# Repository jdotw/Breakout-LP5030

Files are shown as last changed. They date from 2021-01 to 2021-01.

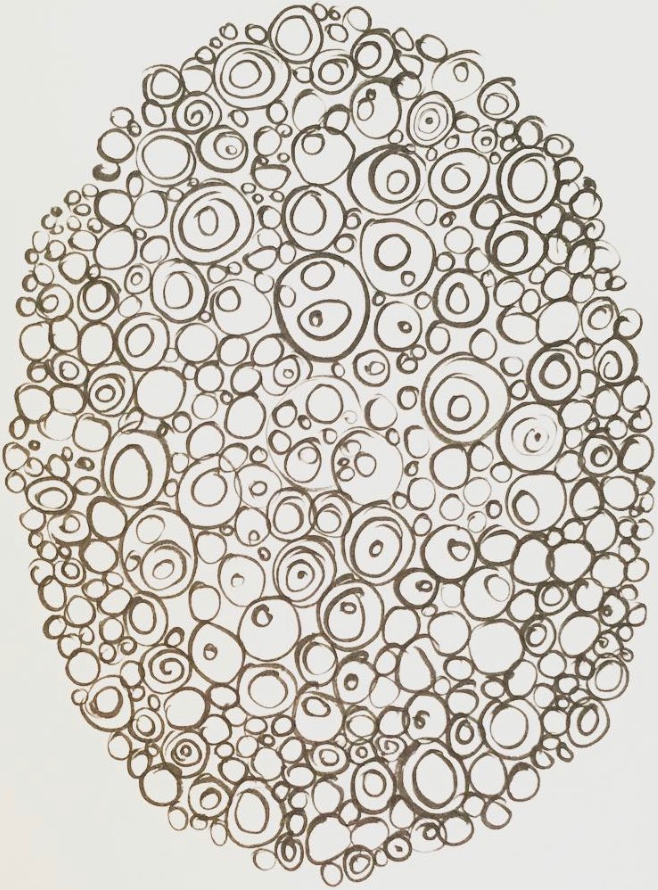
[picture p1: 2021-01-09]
BackImage.png

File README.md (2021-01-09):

# MP2359, LP5030 and TCA9544A Breakout Board

This breakout board allows you to test an LP5030 LED driver, with a TCA9544A i2c mux/hub, being powered by a MP2359 buck power converter. The board was design to be powered by +12V, but should work with anything from +5 to +12. Place a jumper across the 3.3V 2-pin header to enable the use of the onboard power supply. Or, supply 3.3V directly to the pin marked 3.3V to bypass the onboard power supply. 

I built this board because of a larger project where I wanted to use these three components. However, having not used them before in a design and without access to well priced evaluation board, I decided to make my own. TI sells an eval board for the LP5030 but it's $100+ which is ridiculous. There is a well priced board available to eval the MP2359 but it's rather huge. And so, I decided to build my own. 

The gerber and assembly files included herein have been successfully used with JLCPCB and their SMT Assembly surface to order these boards with everything but the LP5030, TCA9544A and headers already assembled. Those, you'll need to take care of yourself. 

If you have any questions you can find me on Twitter @scotchandcode, and streaming regularly at twitch.tv/jdotw. 

Datasheet links:

MP2359: https://www.monolithicpower.com/en/mp2359.html

LP5030: https://www.ti.com/product/LP5030

TCA9544A: https://www.ti.com/product/TCA9544A

Enjoy! 

-jw

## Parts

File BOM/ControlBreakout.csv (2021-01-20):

Comment | Designator | Footprint | LCSC
100nF | C1 | Capacitor_SMD:C_0402_1005Metric | C1525
1uF | C2 | Capacitor_SMD:C_0402_1005Metric | C52923
10uF | C4,C7,C8 | Capacitor_SMD:C_1206_3216Metric | C13585
100nF | C3,C5 | Capacitor_SMD:C_0603_1608Metric | C14663
10nF | C6 | Capacitor_SMD:C_0805_2012Metric | C1710
10uF | C9 | Capacitor_SMD:C_0603_1608Metric | C19702
FM-B2020RGBA-HG | D1,D2,D3,D4,D5,D6,D7,D8,D10,D11 | fm-b2020rgba-hg:FM-B2020RGBA-HG | C108793
LED | D12 | LED_SMD:LED_0603_1608Metric | C72041
B5819W | D9 | Diode_SMD:D_SOD-123 | C8598
500mA | F1 | Fuse:Fuse_1206_3216Metric | C369159
600 @ 600 | FB1 | Inductor_SMD:L_0805_2012Metric | C1017
Conn_01x12 | J1,J2 | Connector_PinHeader_2.54mm:PinHeader_1x12_P2.54mm_Vertical
3v3 Bypass | J3 | Connector_PinHeader_2.54mm:PinHeader_1x02_P2.54mm_Vertical
GND1 | J4 | Connector_PinHeader_2.54mm:PinHeader_1x02_P2.54mm_Vertical
GND2 | J5 | Connector_PinHeader_2.54mm:PinHeader_1x02_P2.54mm_Vertical
Screw_Terminal_01x02 | J6 | TerminalBlock:TerminalBlock_bornier-2_P5.08mm
GND3 | J7 | Connector_PinHeader_2.54mm:PinHeader_1x02_P2.54mm_Vertical
10uH | L1 | Inductor_SMD:L_Sunlord_MWSA0518_5.4x5.2mm | C139506
AO3401A | Q1 | Package_TO_SOT_SMD:SOT-23 | C15127
3.3K | R1 | Resistor_SMD:R_0603_1608Metric | C22978
10K | R2 | Resistor_SMD:R_0603_1608Metric | C25804
100K | R3 | Resistor_SMD:R_1206_3216Metric | C17900
68K | R4 | Resistor_SMD:R_0603_1608Metric | C23231
47K | R5 | Resistor_SMD:R_0603_1608Metric | C25819
15K | R6 | Resistor_SMD:R_0603_1608Metric | C22809
270R | R7 | Resistor_SMD:R_0603_1608Metric | C22966
1K | R8 | Resistor_SMD:R_0603_1608Metric | C21190
100K | R9 | Resistor_SMD:R_0603_1608Metric | C25803
TCA9544A | U1 | Package_SO:TSSOP-20_4.4x6.5mm_P0.65mm
MP2359DJ-LF-Z | U3 | Package_TO_SOT_SMD:TSOT-23-6 | C14259
IS32FL3237-TQLA3-TR | U4 | Package_QFP:TQFP-48-1EP_7x7mm_P0.5mm_EP5x5mm

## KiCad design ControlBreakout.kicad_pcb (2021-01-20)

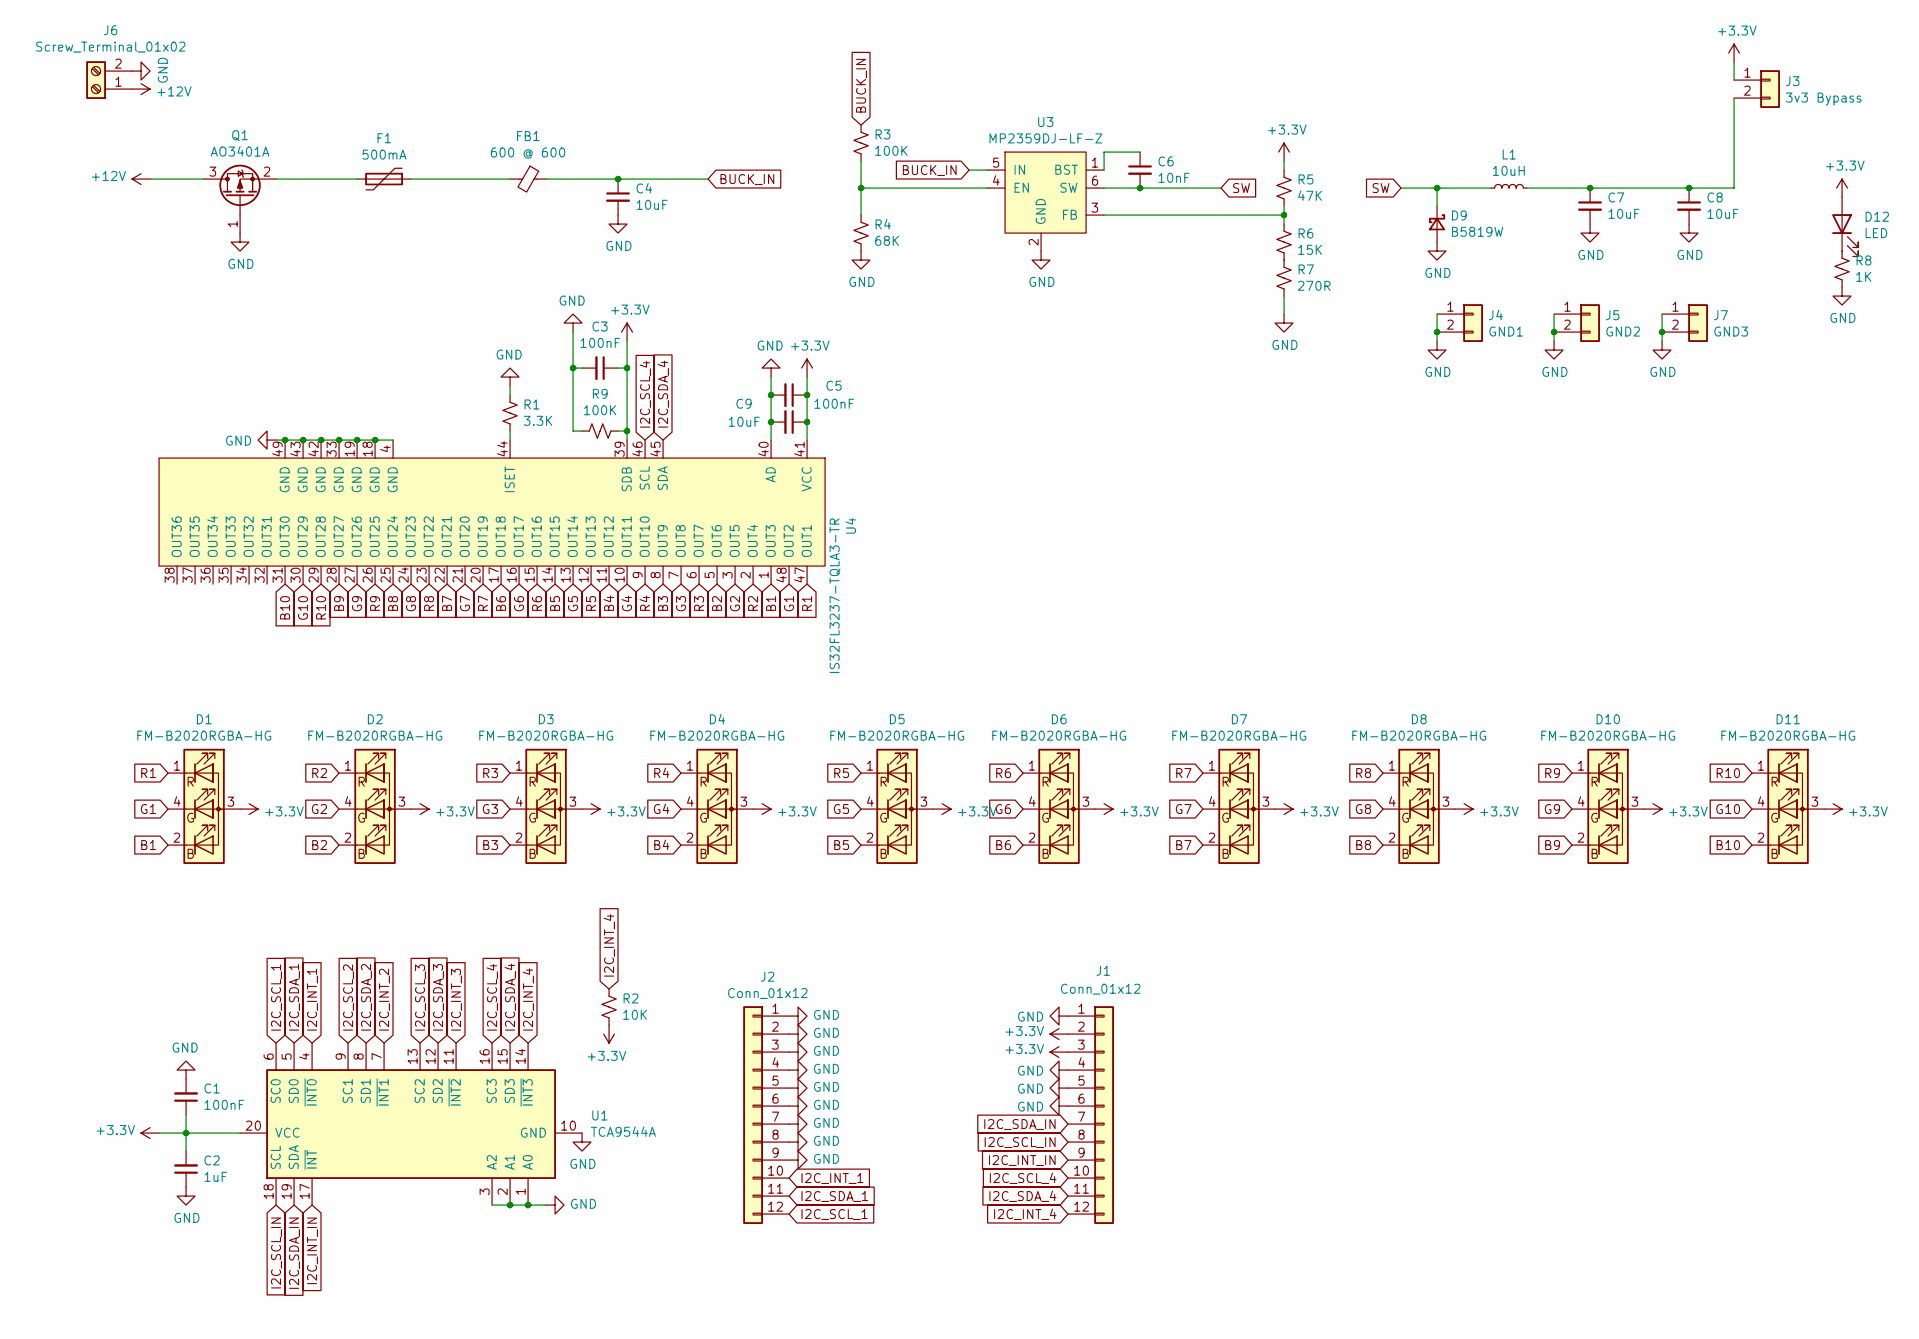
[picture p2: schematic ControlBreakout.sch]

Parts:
C1: 100nF; C_0402_1005Metric; LCSC C1525
C2: 1uF; C_0402_1005Metric; LCSC C52923
C3, C5: 100nF; C_0603_1608Metric; LCSC C14663
C4: 10uF; C_1206_3216Metric; LCSC C13585
C6: 10nF; C_0805_2012Metric; LCSC C1710
C7, C8: 10uF; C_1206_3216Metric; LCSC C19702
C9: 10uF; C_0603_1608Metric; LCSC C19702
D1, D2, D4, D5, D6, D7, D8, D10, D11: FM-B2020RGBA-HG; LCSC C108793
D3: FM-B2020RGBA-HG
D9: B5819W; D_SOD-123; LCSC C8598
D12: LED; LED_0603_1608Metric; LCSC C72041
F1: 500mA; Fuse_1206_3216Metric; LCSC C369159
FB1: 600 @ 600; L_0805_2012Metric; LCSC C1017
J1, J2: Conn_01x12; PinHeader_1x12_P2.54mm_Vertical
J3: 3v3 Bypass; PinHeader_1x02_P2.54mm_Vertical
J4: GND1; PinHeader_1x02_P2.54mm_Vertical
J5: GND2; PinHeader_1x02_P2.54mm_Vertical
J6: Screw_Terminal_01x02; TerminalBlock_bornier-2_P5.08mm
J7: GND3; PinHeader_1x02_P2.54mm_Vertical
L1: 10uH; L_Sunlord_MWSA0518_5.4x5.2mm; LCSC C139506
Q1: AO3401A; SOT-23; LCSC C15127
R1: 3.3K; R_0603_1608Metric; LCSC C22978
R2: 10K; R_0603_1608Metric; LCSC C25804
R3: 100K; R_1206_3216Metric; LCSC C17900
R4: 68K; R_0603_1608Metric; LCSC C23231
R5: 47K; R_0603_1608Metric; LCSC C25819
R6: 15K; R_0603_1608Metric; LCSC C22809
R7: 270R; R_0603_1608Metric; LCSC C22966
R8: 1K; R_0603_1608Metric; LCSC C21190
R9: 100K; R_0603_1608Metric; LCSC C25803
U1: TCA9544A; TSSOP-20_4.4x6.5mm_P0.65mm
U3: MP2359DJ-LF-Z; TSOT-23-6; LCSC C14259
U4: IS32FL3237-TQLA3-TR; TQFP-48-1EP_7x7mm_P0.5mm_EP5x5mm

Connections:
+3V3: C1.1, C2.2, C3.1, C5.1, C9.1, D1.3 (+), D2.3 (+), D3.3 (+), D4.3 (+), D5.3 (+), D6.3 (+), D7.3 (+), D8.3 (+), D10.3 (+), D11.3 (+), D12.2 (A), J1.2, J1.3, J3.1, R2.2, R5.1, R9.2, U1.20 (VCC), U4.39 (SDB), U4.41 (VCC)
+12V: J6.1, Q1.3 (D)
B1: D1.2 (B-), U4.1 (OUT3)
B2: D2.2 (B-), U4.5 (OUT6)
B3: D3.2 (B-), U4.8 (OUT9)
B4: D4.2 (B-), U4.11 (OUT12)
B5: D5.2 (B-), U4.14 (OUT15)
B6: D6.2 (B-), U4.17 (OUT18)
B7: D7.2 (B-), U4.22 (OUT21)
B8: D8.2 (B-), U4.25 (OUT24)
B9: D10.2 (B-), U4.28 (OUT27)
B10: D11.2 (B-), U4.31 (OUT30)
BUCK_IN: C4.1, FB1.1, R3.1, U3.5 (IN)
G1: D1.4 (G-), U4.48 (OUT2)
G2: D2.4 (G-), U4.3 (OUT5)
G3: D3.4 (G-), U4.7 (OUT8)
G4: D4.4 (G-), U4.10 (OUT11)
G5: D5.4 (G-), U4.13 (OUT14)
G6: D6.4 (G-), U4.16 (OUT17)
G7: D7.4 (G-), U4.21 (OUT20)
G8: D8.4 (G-), U4.24 (OUT23)
G9: D10.4 (G-), U4.27 (OUT26)
G10: D11.4 (G-), U4.30 (OUT29)
GND: C1.2, C2.1, C3.2, C4.2, C5.2, C7.2, C8.2, C9.2, D9.2 (A), J1.1, J1.4, J1.5, J1.6, J2.1, J2.2, J2.3, J2.4, J2.5, J2.6, J2.7, J2.8, J2.9, J4.1, J4.2, J5.1, J5.2, J6.2, J7.1, J7.2, Q1.1 (G), R1.1, R4.2, R7.2, R8.2, R9.1, U1.1 (A0), U1.2 (A1), U1.3 (A2), U1.10 (GND), U3.2 (GND), U4.4 (GND), U4.18 (GND), U4.19 (GND), U4.33 (GND), U4.40 (AD), U4.42 (GND), U4.43 (GND), U4.49 (GND)
I2C_INT_1: J2.10, U1.4 (~INT0)
I2C_INT_2: U1.7 (~INT1)
I2C_INT_3: U1.11 (~INT2)
I2C_INT_4: J1.12, R2.1, U1.14 (~INT3)
I2C_INT_IN: J1.9, U1.17 (~INT)
I2C_SCL_1: J2.12, U1.6 (SC0)
I2C_SCL_2: U1.9 (SC1)
I2C_SCL_3: U1.13 (SC2)
I2C_SCL_4: J1.10, U1.16 (SC3), U4.46 (SCL)
I2C_SCL_IN: J1.8, U1.18 (SCL)
I2C_SDA_1: J2.11, U1.5 (SD0)
I2C_SDA_2: U1.8 (SD1)
I2C_SDA_3: U1.12 (SD2)
I2C_SDA_4: J1.11, U1.15 (SD3), U4.45 (SDA)
I2C_SDA_IN: J1.7, U1.19 (SDA)
unnamed: C6.1, U3.1 (BST)
unnamed: C7.1, C8.1, J3.2, L1.2
unnamed: D12.1 (K), R8.1
unnamed: F1.1, FB1.2
unnamed: F1.2, Q1.2 (S)
unnamed: R1.2, U4.44 (ISET)
unnamed: R3.2, R4.1, U3.4 (EN)
unnamed: R5.2, R6.1, U3.3 (FB)
unnamed: R6.2, R7.1
R1: D1.1 (R-), U4.47 (OUT1)
R2: D2.1 (R-), U4.2 (OUT4)
R3: D3.1 (R-), U4.6 (OUT7)
R4: D4.1 (R-), U4.9 (OUT10)
R5: D5.1 (R-), U4.12 (OUT13)
R6: D6.1 (R-), U4.15 (OUT16)
R7: D7.1 (R-), U4.20 (OUT19)
R8: D8.1 (R-), U4.23 (OUT22)
R9: D10.1 (R-), U4.26 (OUT25)
R10: D11.1 (R-), U4.29 (OUT28)
SW: C6.2, D9.1 (K), L1.1, U3.6 (SW)

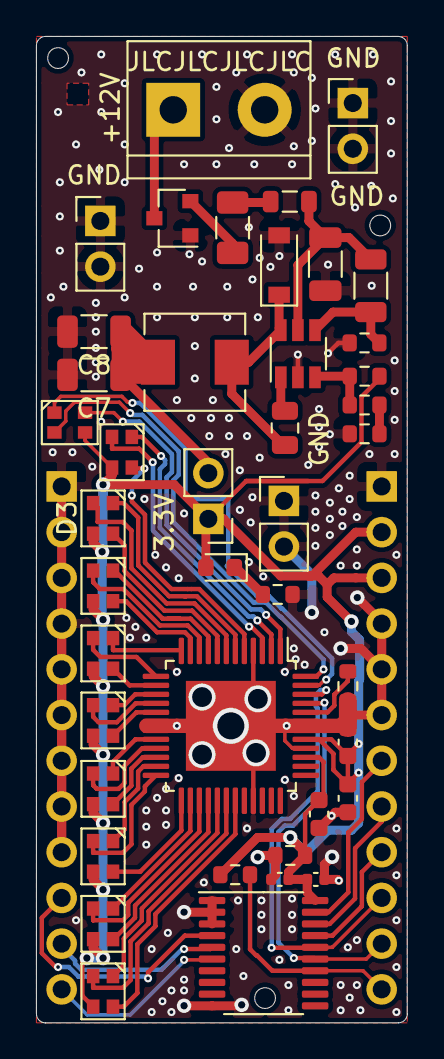
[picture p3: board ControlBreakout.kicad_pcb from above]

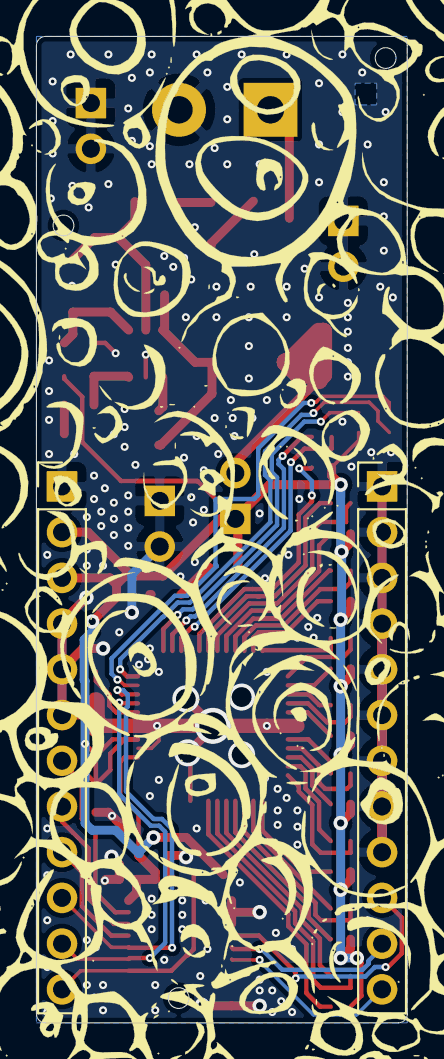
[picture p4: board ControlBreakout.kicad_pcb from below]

Board: 2 copper layers, 20.6 x 54.8 mm, 44 parts (2 on the bottom side), 53 nets.

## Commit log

2021-01-09 Breakout board for MP2359 power regulator, LP5030 LED driver, and TCA9544A i2c mux
    [ControlBreakout-B_Cu.gbr, ControlBreakout-B_Mask.gbr, ControlBreakout-B_Paste.gbr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]
2021-01-18 Version 1
    [ControlBreakout.kicad_pcb]
2021-01-20 nearly done on v2
    [ControlBreakout-B_Cu.gbr, ControlBreakout-B_Mask.gbr, ControlBreakout-B_Paste.gbr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]
2021-01-20 First attempt at ordering
    [ControlBreakout-B_Cu.gbr, ControlBreakout-B_Mask.gbr, ControlBreakout-B_Paste.gbr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]
